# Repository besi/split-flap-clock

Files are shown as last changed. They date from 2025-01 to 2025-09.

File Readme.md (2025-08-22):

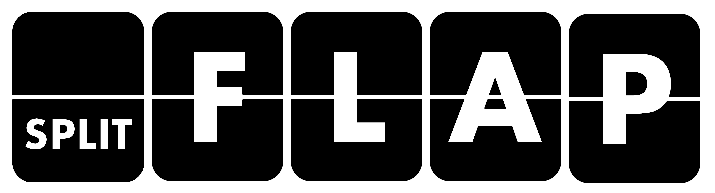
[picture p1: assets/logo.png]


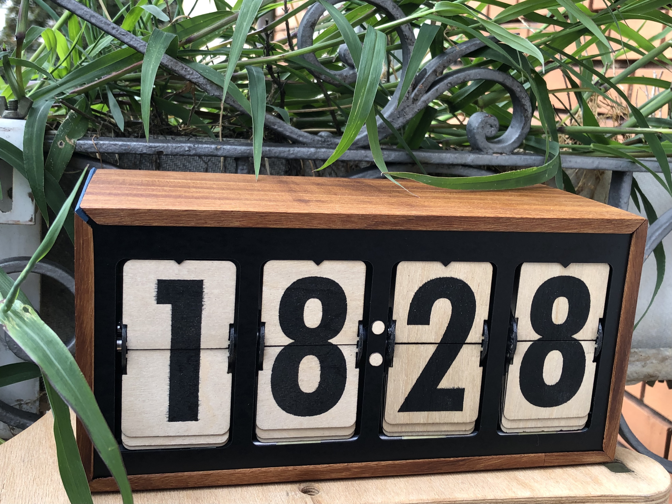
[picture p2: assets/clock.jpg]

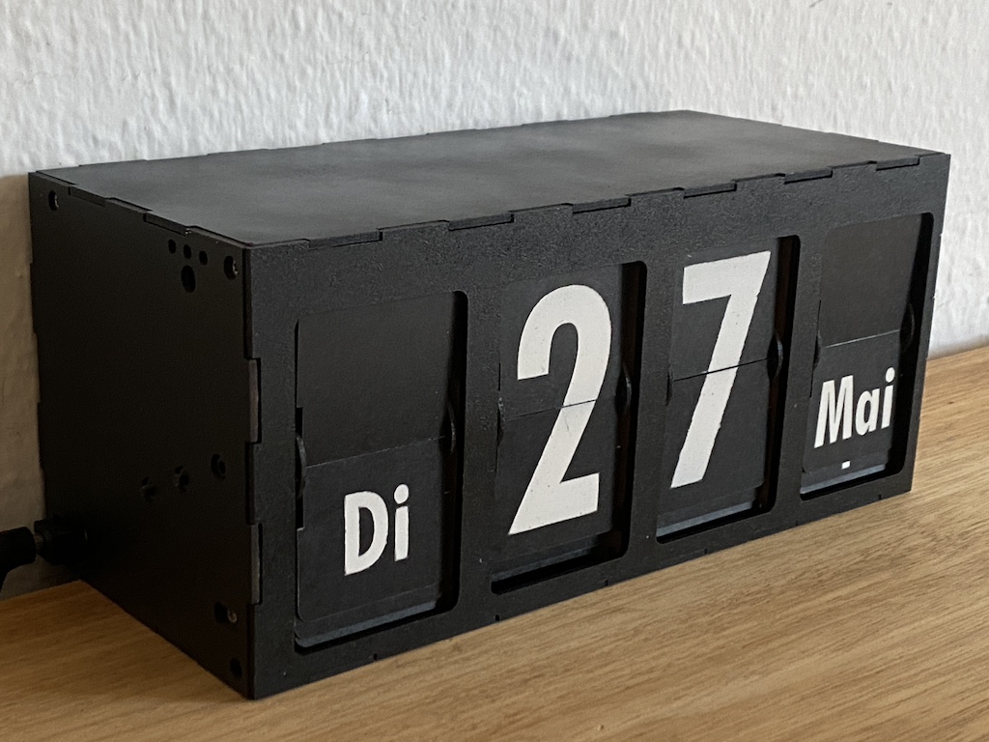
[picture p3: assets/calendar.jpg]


Split Flap clock or calendar utilising four 28BYJ-48 stepper motors.

## Bill of materials

What is needed for one digit.

| Count | Item | Description |
|---|---|---|
| 1 | PCB v2.0 | |
| 1 | Supporting Plate | Same shape and holes like the PCB |
| 1 | Spacer 2mm | Spacer for cogwheels |
| 1 | Hall sensor AH1815-W7| For the unpopulated PCBs only |
| 1 | 10k Resistor 0306 | For the unpopulated PCBS |
| 1 | Spool | 3-D Print with M3 heat insert |
| 1 | Spool lid | 3-D Print |
| 1 | Cog Stepper | 3-D Print / Laser cut |
| 1 | Cog M3 | 3-D Print / Laser cut |
| 1 | Cog M3 Nut | 3-D Print / Laser cut |
| 1 | Magnet 2x1mm | For spool |
| 1 | Motor 28BYJ-48 | 5V Version |
| 1 | Motor gasket | Laser cut |
| 12 | Flaps | Laser cut Flaps |
| 1 | 3 Pos JST 2mm Socket | Hall sensor Connection |
| 1 | 3 Pos JST 2mm Cable  | Hall sensor Connection |
| 4 | M3 Nuts | 2 Cogs, 2 Motor |
| 5 | M3x8mm Bolt | 2 Cogs,2 Motor, Spindle, |
| 3 | M3x5mm Bolt | 3 Spindle |
| 4 | M3 Standoffs 50mm | Male-Female 6mm thread |
| 4 | M2.5 Screws | For Standoffs |
| 1 | Washer 5mm 1mm thick | For Driver cogwheel |
| 2 | Washer 3mm 1mm thick | For cogwheels |
| 1 | Zip tie for motor | |

## Pinout

Motors: 

| Pins | 1  | 2  | 3  | 4  | Hall  |
|---|----|----|----|----|---|
| **Motor A** | 10 | 9  | 3  | 8  | 18 (7)|
| **Motor B** | 13 | 14 | 21 | 11 | 12 |
| **Motor C** | 40 | 39 | 38 | 6  | 47 |
| **Motor D** | 1  | 2  | 42 | 41 | 48 |

Other GPIOs

| Function | Pin |
|---|-----|
| DCF-77 | 4 |
| SDA / Switch B | 16  |
| SCL / Switch A | 17  |
| Mode | 0 |
| Neopixel | 15  |
| Temperature | 5 |

## Assembly

One assembled PCB which functions as the main board can drive four split flap digits including itself as well as three additional passive digits. Looking from the front of the clock / calendar the unit with the populated PCB is to the very left with the barrel jack protruding outward to the left side.

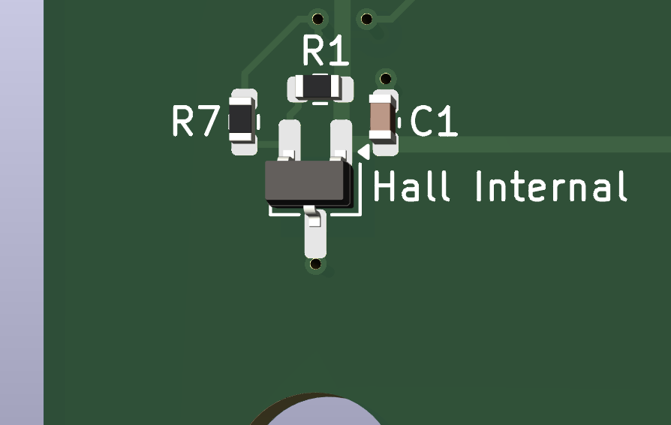
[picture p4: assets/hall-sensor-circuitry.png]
a
- On the three unpopulated PCBs the Hall sensors circuitry above the spool axis has to be provided. For this R7 can be shortened using a solder bridge, the Hall sensor (AH1815-W7) as well as the R1 resistor (10k 0603) need to be mounted. C1 (100nF 0603) can be omitted:  

- Using M3x5 screws mount all four motors directly to the corresponding PCB using the spacer where it says "28BYJ-48". The nuts go to the other side of the PCB where the spacer has two cutouts for both nuts.

- On the main board connect the motor to the "Motor A" connector. The cable can be looped and secured using a zip tie threaded through the two holes next to the motor.

- On the main board solder the three switches and the RGB LED to the backside of the PCB.

- Solder the DCF77 connector to the pcb and temporarily tape the ferrite antenna to the PCB to protect the thin copper wires from the coil around the antenna.

- Add cog wheels with the M3x8 screws on two different sides
- Add the spacer
- Add the cover
- Connect all hall sensors
- Prepare the spool 
- Add standoffs female-female or standoffs male-female respectively

- The driving cog wheel is assembled as follows:

        M3x16 + 5 washers + m3-nut-cog + 3 washers

## The PCB

[PCBWay][pcbway] kindly offered to sponsor the manufacturing and assembly of the second iteration of this pcb.

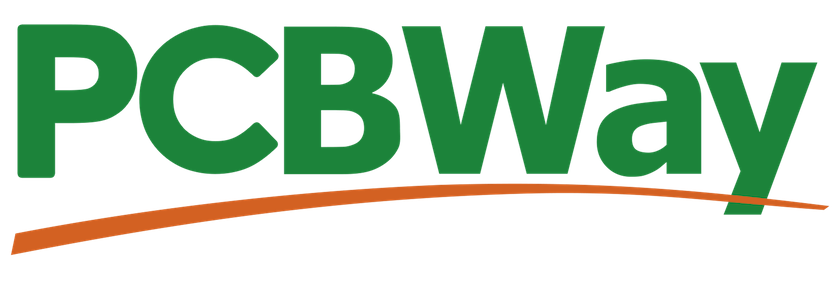
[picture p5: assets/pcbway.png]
PCBWay
[][pcbway]

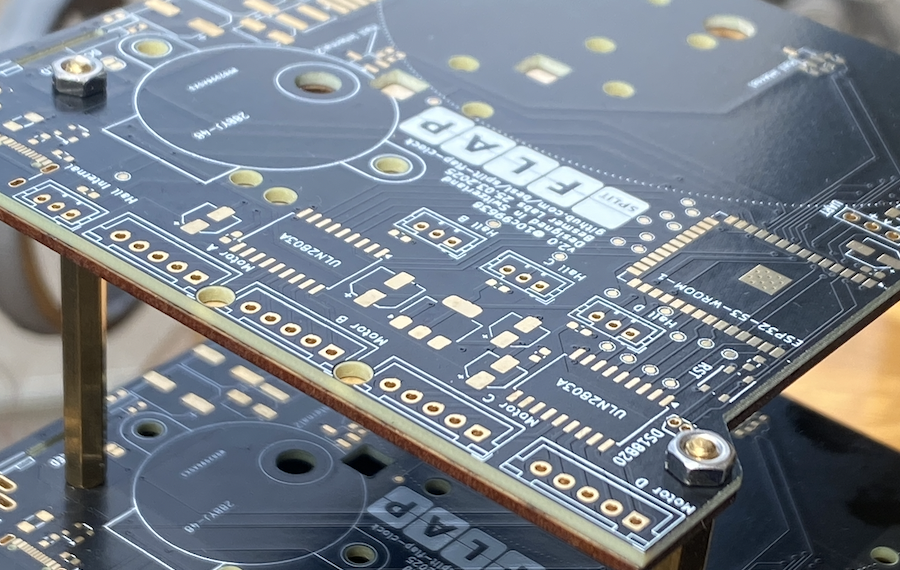
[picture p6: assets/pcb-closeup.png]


In this project the PCBs are used in both the electrical as well as the mechanical realm. The motors and cog wheels are directly mounted onto the pcb and for one clock or calendar four pcbs are stacked together.

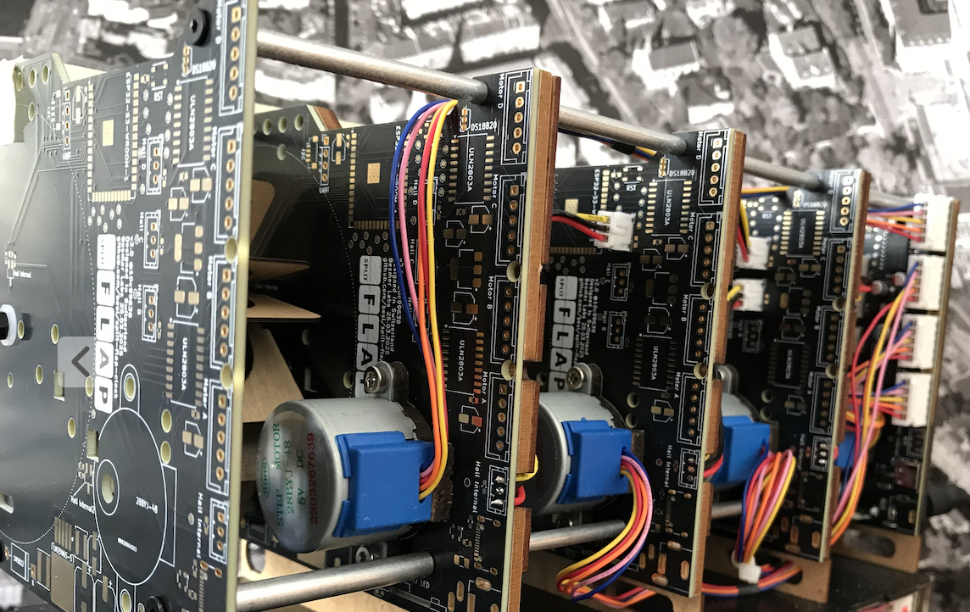
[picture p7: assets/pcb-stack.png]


The PCBs turned out flawlessly and the ordering process was smooth and efficient.

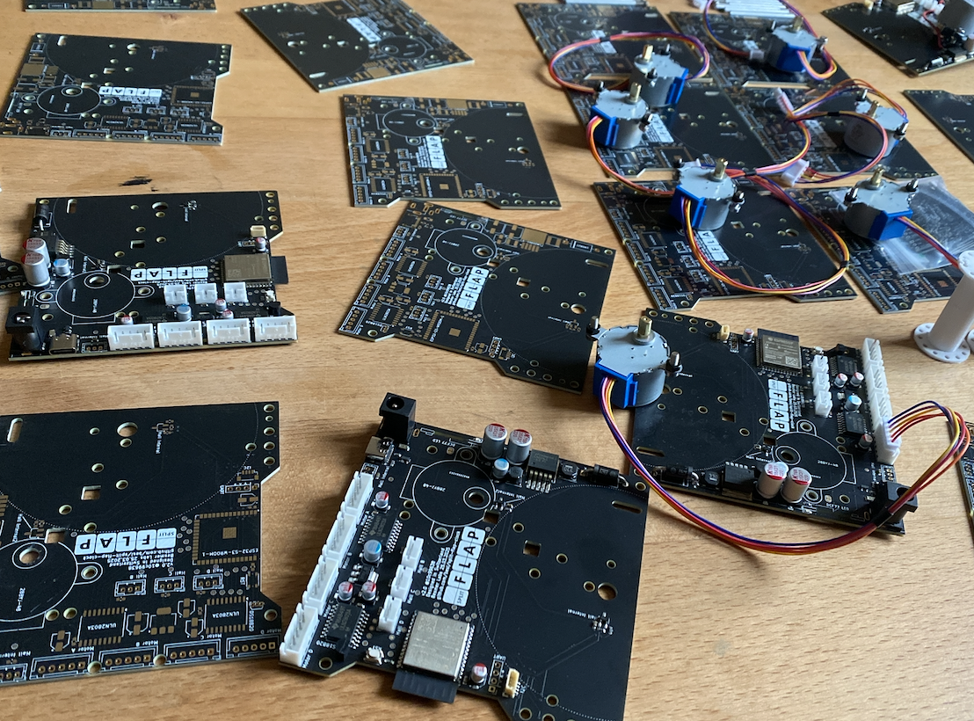
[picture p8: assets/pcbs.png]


[pcbway]: https://pcbway.com/g/2jc702

### PCB V2.0
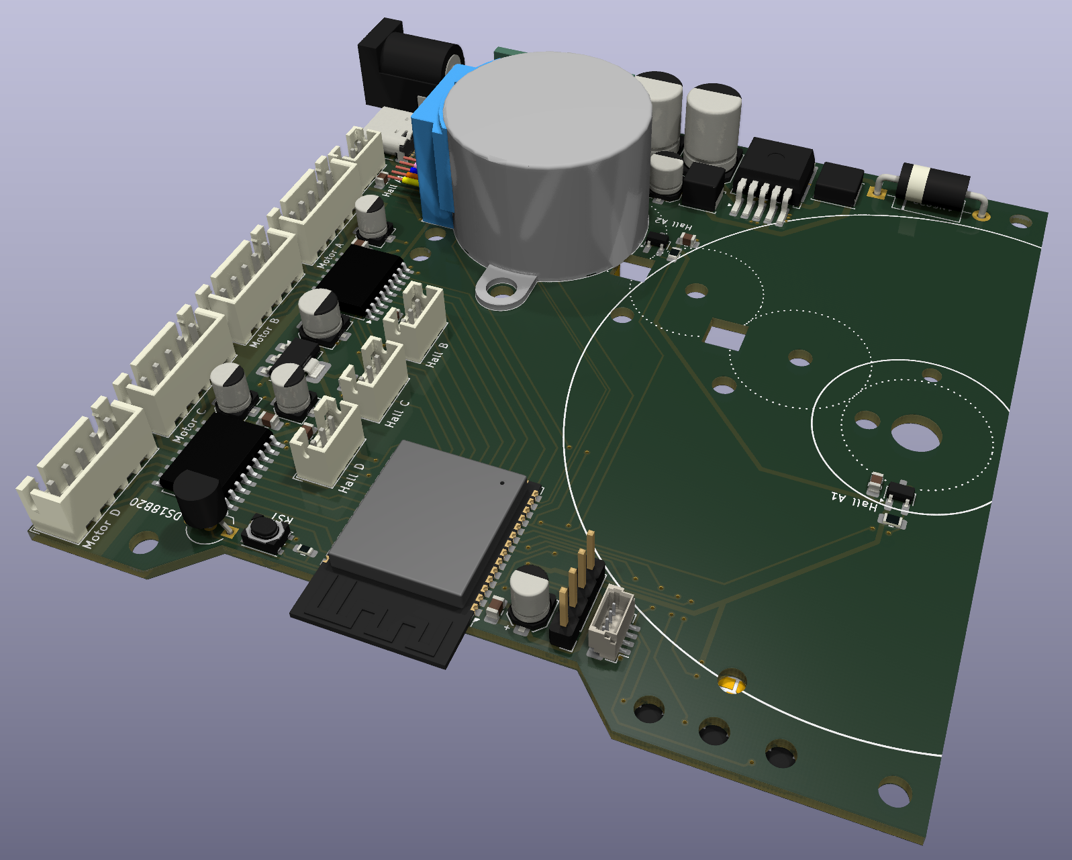
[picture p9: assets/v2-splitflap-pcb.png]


### PCB V1.0

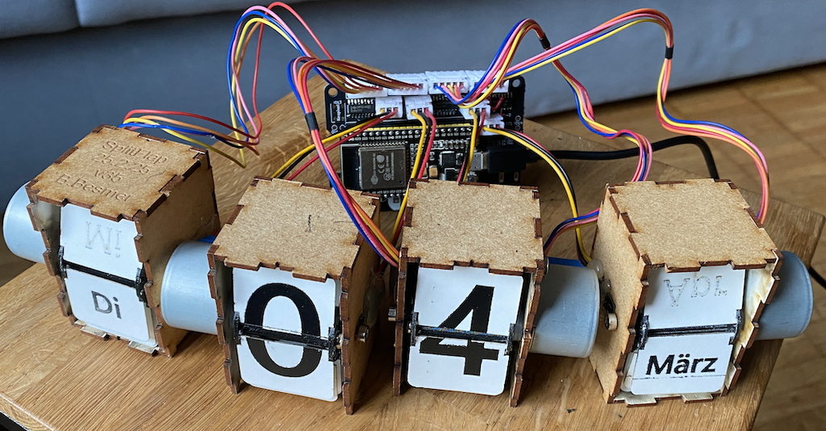
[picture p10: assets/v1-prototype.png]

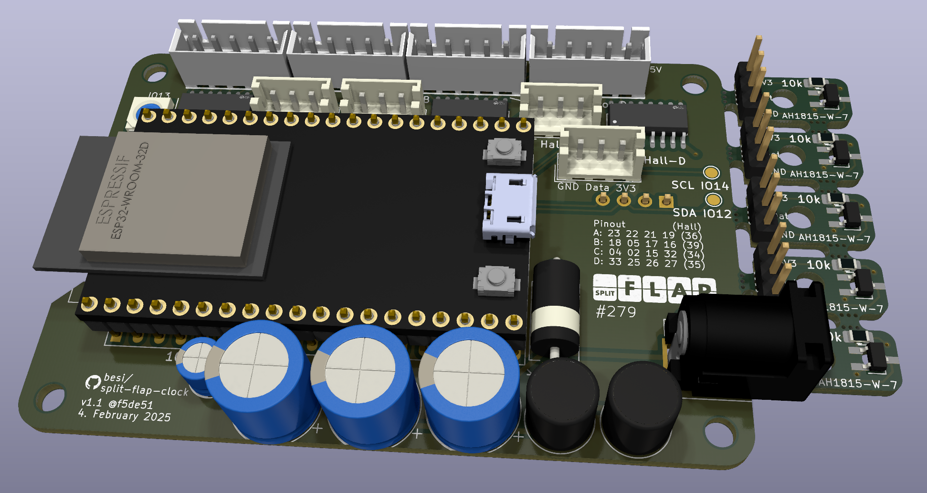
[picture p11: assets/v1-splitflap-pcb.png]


## Flashing the PCB

    cd ~/Downloads
    IMAGE=ESP32_GENERIC_S3-FLASH_4M-20250415-v1.25.0.bin
    wget https://micropython.org/resources/firmware/$IMAGE -nc
    PORT=/dev/cu.usbmodem14401
    esptool.py --port $PORT erase_flash
    esptool.py --port $PORT --baud 460800 write_flash --flash_size=detect 0 $IMAGE --flash_mode=dout

## Credits / Thanks

### Troubleshooting

Special thanks to [greybeard](https://electronics.stackexchange.com/users/274544/greybeard) and [KubaO](https://electronics.stackexchange.com/users/10810/kuba-hasnt-forgotten-monica) who helped to [trouble shoot](https://electronics.stackexchange.com/questions/740221/cross-talk-issues-with-uln2003-and-28byj-48-stepper) some serious issues that arose during the development of the PCB.

### 3D models
- Credits for the [ESP32 Devkit 3d model](https://grabcad.com/library/esp32-devkitc-v4-1) by [Andrei Golyakov](https://grabcad.com/andrei.golyakov-1)
- Credits for the [SK6814mini 3d model](https://grabcad.com/library/sk6812-mini-sk6814-smd3535-1) by [Laur V](https://grabcad.com/laur.v-1)

### Markdown tables

The Markdown tables were generated using the fabulous tool called [tableconvert](https://tableconvert.com/markdown-generator).

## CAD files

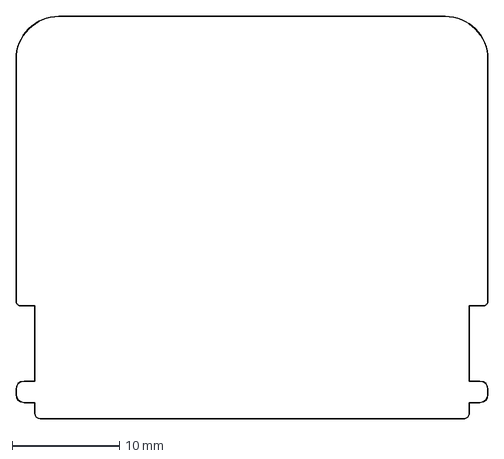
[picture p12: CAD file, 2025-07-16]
dxf/v2/Flap.dxf
44.0 x 37.5 mm

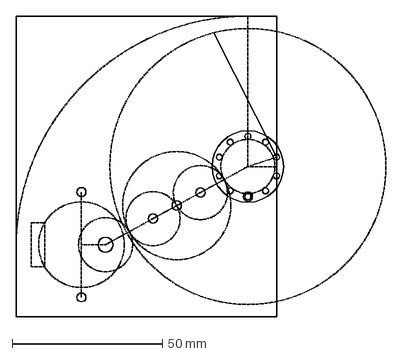
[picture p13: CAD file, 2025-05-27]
stl/v1-2/PCBOutline.dxf
122.9 x 100.0 mm

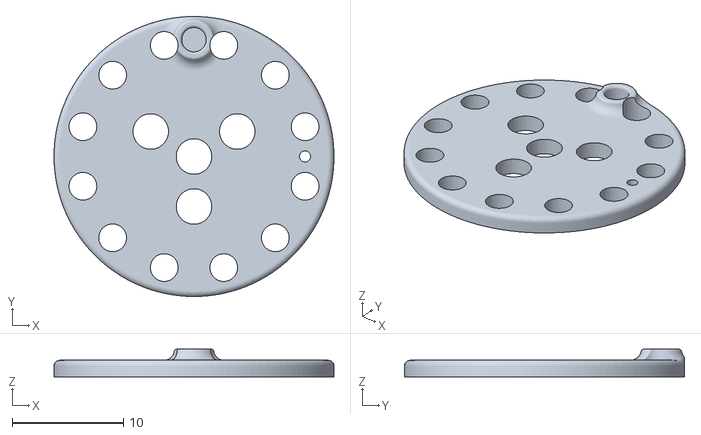
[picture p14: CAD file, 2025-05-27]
stl/v2/spool-lid.stl
25.2 x 25.2 x 2.50

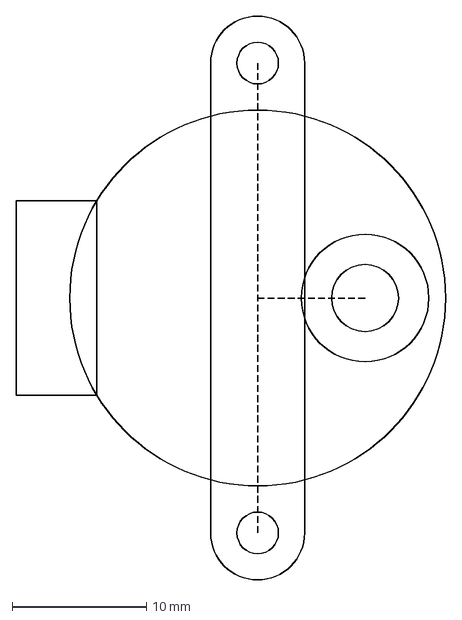
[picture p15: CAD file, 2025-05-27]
dxf/v2/MotorSpacerCork-T1.dxf
32.0 x 42.0 mm

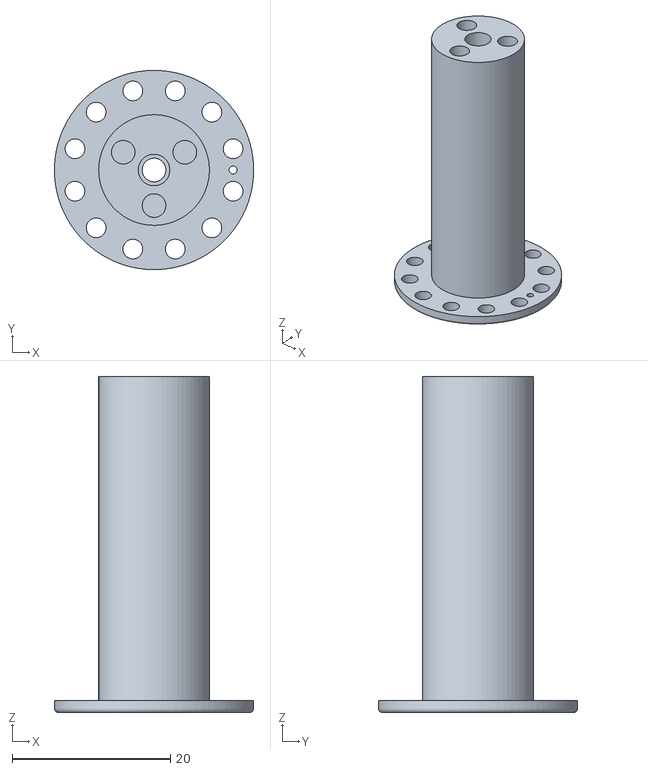
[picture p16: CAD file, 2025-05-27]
stl/v2/spool-base.stl
25.2 x 25.2 x 42.5

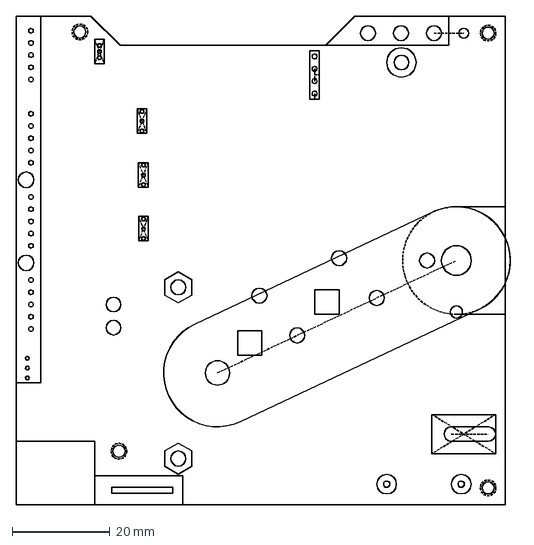
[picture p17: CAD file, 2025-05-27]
dxf/v2/Backplate-Spacer-T3.dxf
102.5 x 100.0 mm

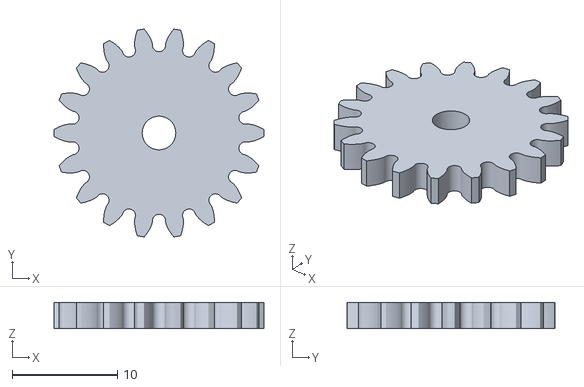
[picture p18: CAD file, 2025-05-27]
stl/v2/cog-n18-m1-t1-8-hole-m3.stl
20.0 x 19.8 x 2.50

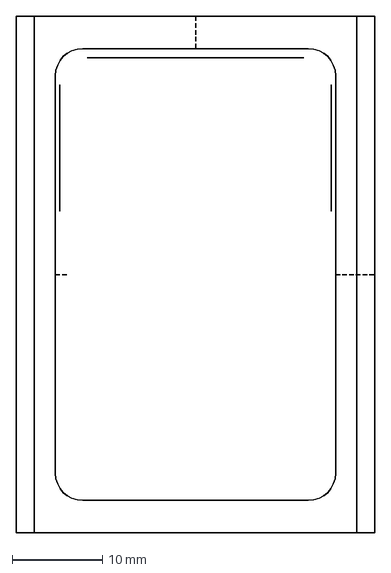
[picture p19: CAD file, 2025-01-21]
dxf/v2/2mm-front.dxf
39.7 x 57.1 mm

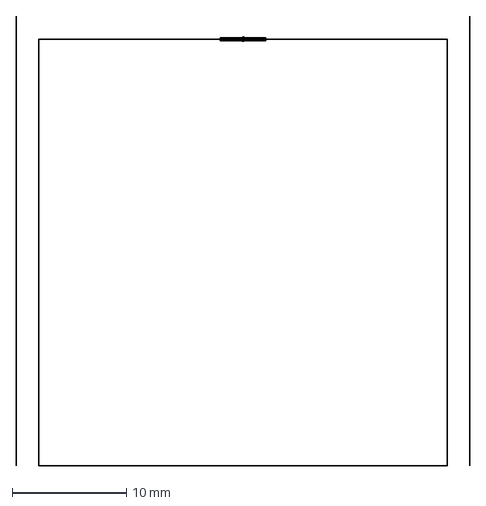
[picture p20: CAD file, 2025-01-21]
dxf/v2/2mm-top.dxf
39.7 x 39.3 mm

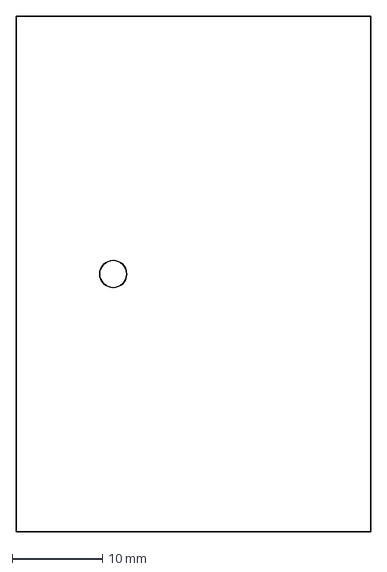
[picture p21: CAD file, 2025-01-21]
dxf/v2/2mm-right.dxf
39.3 x 57.1 mm

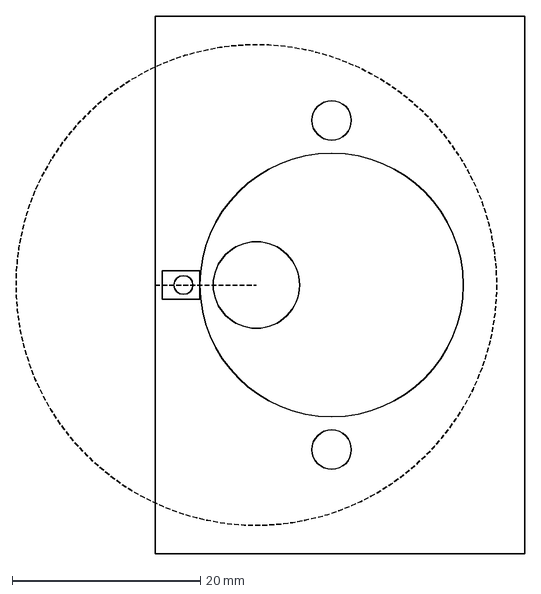
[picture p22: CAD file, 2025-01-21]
dxf/v2/2mm-left.dxf
54.1 x 57.1 mm

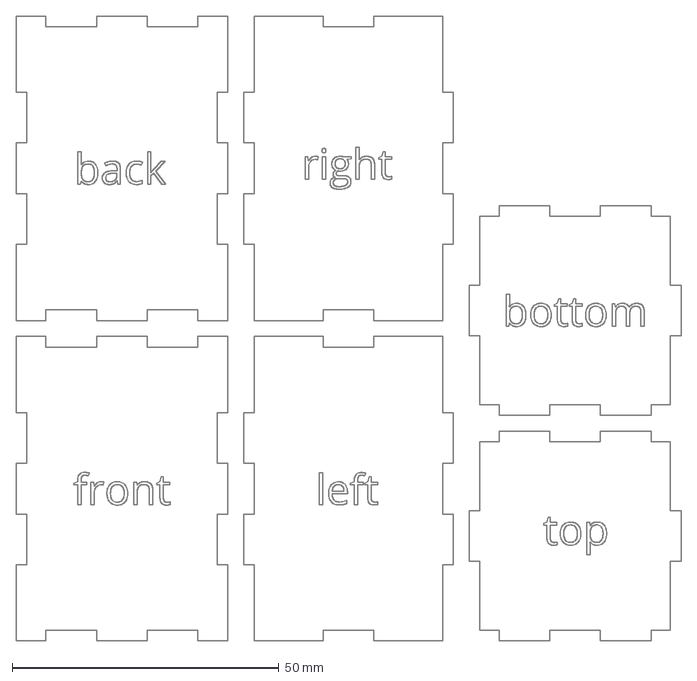
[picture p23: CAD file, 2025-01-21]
dxf/v2/2mm-w39-7-h57.1-d39-32-32-finger-9.5-outside.dxf
124.7 x 117.2 mm

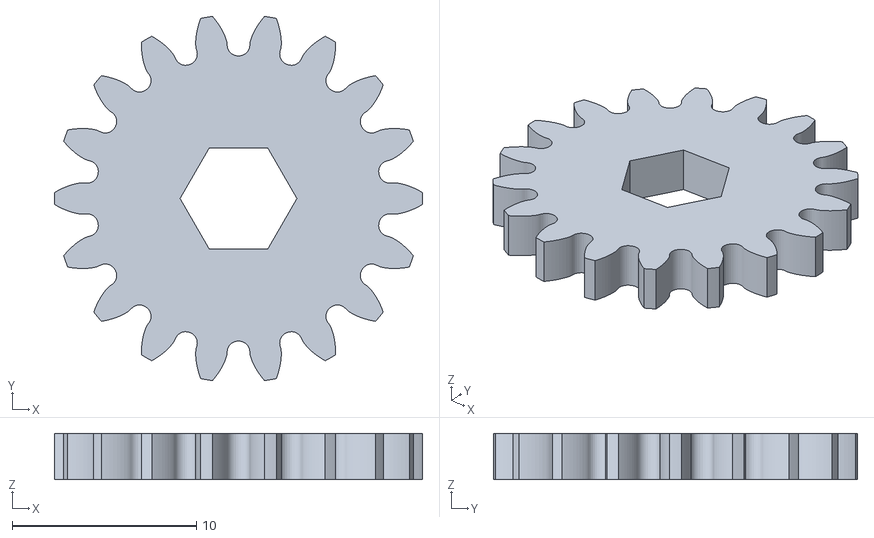
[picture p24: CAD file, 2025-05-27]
stl/v2/cog-n18-m1-t1-8-m3-nut.stl
20.0 x 19.8 x 2.50

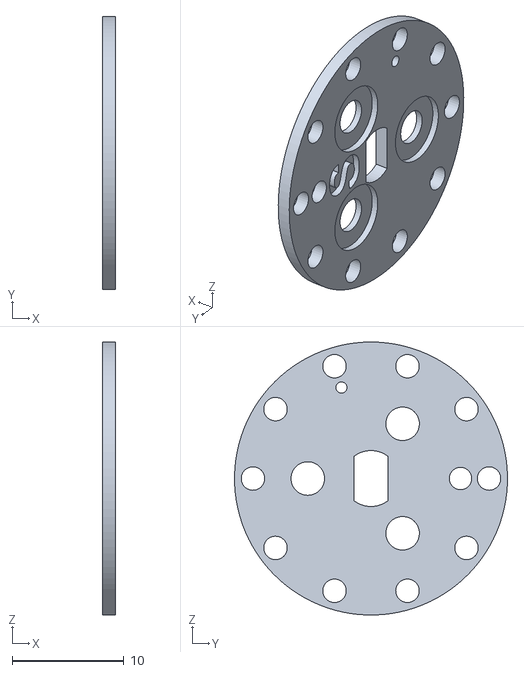
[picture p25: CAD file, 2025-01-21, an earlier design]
dxf/v1/driving front.stl
1.20 x 24.4 x 24.4

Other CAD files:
dxf/v2/flaps-pair.dxf
dxf/v2/flap-toucher.dxf
stl/v2/cog-n18-m1-t1-8-slotted5mm.stl
dxf/v1/2mm-makercase-outer-40-4--80-9--45-58.dxf
dxf/v1/2mm-front.dxf
dxf/v1/2mm-left.dxf
dxf/v1/2mm-right.dxf
dxf/v1/3mm-front.dxf
dxf/v1/3mm-left.dxf
dxf/v1/3mm-makercase-outer-3mm-x43-4-y80-9-z47-17.dxf
dxf/v1/3mm-right.dxf

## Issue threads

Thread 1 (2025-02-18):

Hardware test v1.0

besi, 2025-02-18:
- [x] Hall Sensors
- [x] Motor A
- [x] Motor B
- [x] Motor C
- [x] Motor D
- [x] Buttons
- [x] Neopixel not working
- [x] I2C

Results

- [x] #2
- [x] #3

Closed 2025-05-17.

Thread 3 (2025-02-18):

Motors not working due to the wrong package

besi, 2025-02-18:
Stepomatic's ULN2003 seems more narrow and uses by ti 32CCETK ULN2003A

besi, 2025-02-18:
Digikey lists the following packages

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

besi, 2025-02-18:
Package was fixed but there are still problems.

Motor C and Motor D work now on two pcbs

- Motor A: Pin 3 does not work
- Motor B: Pin 2 does not work
- Motor B: Pin 3 do not work

Closed 2025-02-18.

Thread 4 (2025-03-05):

Redesign

besi, 2025-03-05:
The next design iteration should include the following:

- [ ] Include the feedback from the [SO-Thread](https://electronics.stackexchange.com/questions/740221/cross-talk-issues-with-uln2003-and-28byj-48-stepper)
- [ ] Feature some mounts for cog-wheels and possibly the motor for the split flap display
- [ ]

besi, 2025-03-05:
@KubaO have a look at the new design constraints. While my initial design on SO was v1.0 and I might actually order a design 1.1 with your changes in them.

This issue here talks about version 2.0 where the PCB is tightly mechanically integrated in the design.

besi, 2025-03-08:
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

besi, 2025-03-08:
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

besi, 2025-03-10:
@KubaO. I made a draft of a PCB that serves as the mount of the motor and as a structural element. The glassy cylinder is the space that the flaps will occupy. There will be a second pcb without parts sandwiched ontop in order to make a tight enclosure for the gear train and then this will thing can be copy and pasted four times to form one unit.

besi, 2025-03-12:
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

besi, 2025-05-03:
Fixed and proceeding with #7

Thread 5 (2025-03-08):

On the fly calibration

besi, 2025-03-08:
Currently at power up a calibration sequence is done.
However after several turns the spool gets out of phase and some digits fall pre-maturely. Also because 513 / 10 is not a hole number.

- [x] When the spool goes past the known magnet point make a quick calibration and update the zero point

Optional:
- [ ] Compensate the three steps in between moves

besi, 2025-06-15:
If the correction is merely done by changing the position then the digit will update even though the same letter is still displayed.

besi, 2025-06-15:
The correction should be corrected over time by occasionally skipping some steps or doing extra steps.

Closed 2025-06-14.

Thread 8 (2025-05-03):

12V circuitry trips the resettable fuse

besi, 2025-05-03:

besi, 2025-05-03:
A workaround is to separate the 5V circuit from the 12V circuitry

besi, 2025-05-17:
The power socket was soldered on the wrong side of the PCB creating a short.

Closed 2025-05-17.

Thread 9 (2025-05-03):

Flashing poses a problem

besi, 2025-05-03:
When selecting the port there is a message:

invalid header: 0xffffffff
invalid header: 0xffffffff
invalid header: 0xffffffff
invalid header: 0xffESP-ROM:esp32s3-20210327
Build:Mar 27 2021
rst:0x7 (TG0WDT_SYS_RST),boot:0x8 (SPI_FAST_FLASH_BOOT)
Saved PC:0x40048839

besi, 2025-05-03:
After flashing the chip there is a new message:

OSError: (-24579, 'ESP_ERR_FLASH_NOT_INITIALISED')

besi, 2025-05-03:
Try to detect the flash size: does not work
Try with 4MB like the BOM lists:

<!-- Failed to upload "Screenshot 2025-05-03 at 21.20.19.png" -->

besi, 2025-05-03:
Seemed to have bricked one of the boards unixb0y/Micropython-ESP32-S3-WROOM-1-N4#1

besi, 2025-05-04:
Using the 4MB flash image did the trick:
https://micropython.org/resources/firmware/ESP32_GENERIC_S3-FLASH_4M-20250415-v1.25.0.bin

Closed 2025-05-04.

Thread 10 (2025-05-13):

Power issues

besi, 2025-05-13:
Unable to connect to /dev/cu.usbmodem14501: [Errno 2] could not open port /dev/cu.usbmodem14501: [Errno 2] No such file or directory: '/dev/cu.usbmodem14501'

Enabling Wifi seems to draw too much power.

besi, 2025-05-17:
Tried to short the fuse.
No immediate effect

besi, 2025-05-17:
Setting thE RX power

Closed 2025-05-27.

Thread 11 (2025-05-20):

Digit d2 looses steps

besi, 2025-05-20:
Digit 2 looses steps

- [x] Make sure it's not a mechanical issue by switching out two motors and hall sensors

## Observations

- The initial calibration is smooth and quick
- Then the MQTT starts and connects and when a message is received and displayed the display looses steps and displays the wrong numbers.
- In the normal date mode the problem does not seem to occur

## Thoughts

- The Wifi connectivity could be posing some issues since the normal date mode seems to work
- [ ] Use an oscilloscope to check out the signal integrity

besi, 2025-05-20:
The issue was caused due to a software bug which initialised pins from the motor as inputs

Closed 2025-05-20.

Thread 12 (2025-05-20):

Cog screws tighten themselves

besi, 2025-05-20:

besi, 2025-05-20:
A fix would be to mount the cogs with a m3 washer on the inside functioning as an bearing

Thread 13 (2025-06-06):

Infidelities when painting the Flaps

besi, 2025-06-06:
The Laser cutting process has speed and power issues

Small shapes get more power

besi, 2025-06-06:
100 speed
13/11 power has more consistent results

besi, 2025-06-06:
Power below 10 would be helpful

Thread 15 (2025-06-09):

Cogwheels get stuck

besi, 2025-06-09:
Spacer cardboard is 2.8mm

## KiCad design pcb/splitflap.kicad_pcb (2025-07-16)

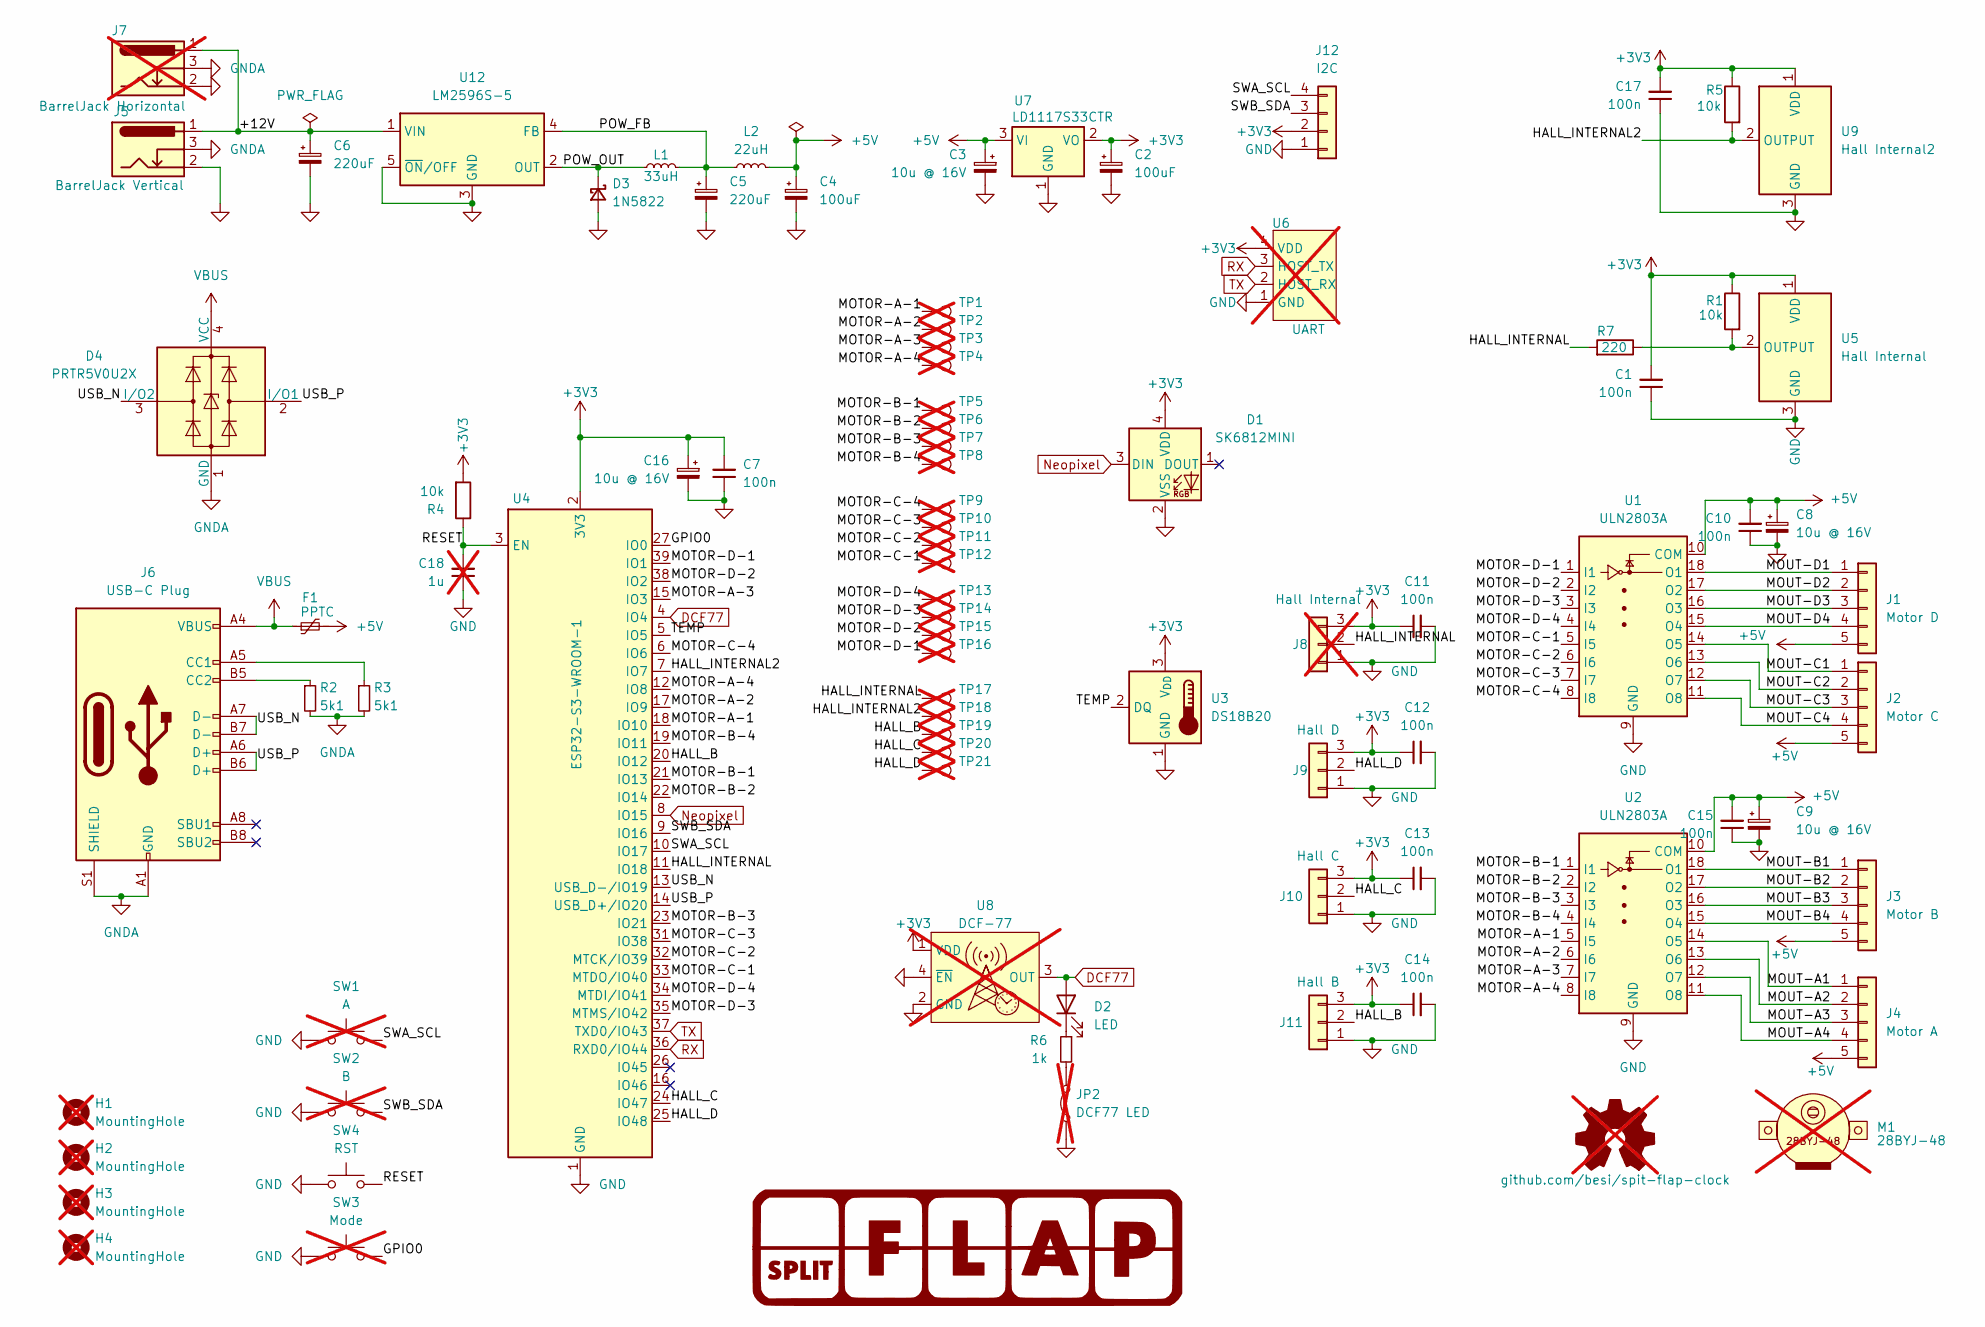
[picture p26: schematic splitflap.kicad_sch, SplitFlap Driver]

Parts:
C1, C7, C10, C11, C12, C13, C14, C15, C17: 100n; C_0603_1608Metric; MPN CL10E104KC8VPNC
C2, C4: 100uF; CP_Elec_5x5.3; MPN APXG160ARA101ME61G
C3, C8, C9, C16: 10u @ 16V; CP_Elec_4x5.7; MPN 865080340001
C5, C6: 220uF; CP_Elec_8x11.9; MPN A768KS227M1VLAE024
C18: 1u; C_0805_2012Metric_Pad1.18x1.45mm_HandSolder; MPN CL21B105KOFNNNG; not fitted
D1: SK6812MINI; LED_SK6812MINI_PLCC4_3.5x3.5mm_P1.75mm; MPN 1528-1541-ND
D2: LED; LED_0603_1608Metric_Pad1.05x0.95mm_HandSolder; MPN 150060RS75000
D3: 1N5822; D_DO-201_P15.24mm_Horizontal; MPN 1N5822
D4: PRTR5V0U2X; SOT-143; MPN PRTR5V0U2X,215
F1: PPTC; Fuse_1206_3216Metric; MPN MF-NSMF110/16X-2
H1, H2, H3, H4: MountingHole; MountingHole_3.2mm_M3; MPN X; LCSC DNP; not fitted
J1: Motor D; JST_XH_B5B-XH-A_1x05_P2.50mm_Vertical; MPN B5B-XH-A
J2: Motor C; JST_XH_B5B-XH-A_1x05_P2.50mm_Vertical; MPN B5B-XH-A
J3: Motor B; JST_XH_B5B-XH-A_1x05_P2.50mm_Vertical; MPN B5B-XH-A
J4: Motor A; JST_XH_B5B-XH-A_1x05_P2.50mm_Vertical; MPN B5B-XH-A
J5: BarrelJack Vertical; pj-060a; MPN CP-060A-ND
J6: USB-C Plug; USB_C_Receptacle_GCT_USB4105-xx-A_16P_TopMnt_Horizontal; MPN USB4105-GF-A
J7: BarrelJack Horizontal; BarrelJack_GCT_DCJ200-10-A_Horizontal; MPN 2073-DCJ200-10-A-K1-K-ND; not fitted
J8: Hall Internal; JST_PH_B3B-PH-K_1x03_P2.00mm_Vertical; MPN B3B-PH-K-S; not fitted
J9: Hall D; JST_PH_B3B-PH-K_1x03_P2.00mm_Vertical; MPN B3B-PH-K-S
J10: Hall C; JST_PH_B3B-PH-K_1x03_P2.00mm_Vertical; MPN B3B-PH-K-S
J11: Hall B; JST_PH_B3B-PH-K_1x03_P2.00mm_Vertical; MPN B3B-PH-K-S
J12: I2C; JST_SH_BM04B-SRSS-TB_1x04-1MP_P1.00mm_Vertical; MPN BM04B-SRSS-TB
JP2: DCF77 LED; SolderJumper-2_P1.3mm_Bridged_RoundedPad1.0x1.5mm; MPN X; not fitted
L1: 33uH; L_APV_ANR6028; MPN NR6028T330M
L2: 22uH; L_APV_ANR5045; MPN TYS5040220M-10
M1: 28BYJ-48; 28byj; MPN 28BYJ-48; not fitted
OSHW1: github.com/besi/spit-flap-clock; OSHW-Symbol_6.7x6mm_SilkScreen; MPN X; not fitted
R1, R5: 10k; R_0603_1608Metric; MPN CR0603-FX-1002ELF
R2, R3: 5k1; R_0603_1608Metric; MPN CR0603-FX-5101ELF
R4: 10k; R_0603_1608Metric_Pad0.98x0.95mm_HandSolder; MPN CR0603-FX-1002ELF
R6: 1k; R_0603_1608Metric; MPN CR0603-JW-102ELF
R7: 220; R_0603_1608Metric; MPN CR0603-JW-221ELF
SW1: A; SW_Push_1P1T_NO_Vertical_Wuerth_434133025816; MPN PTS815SJM250SMTRLFS; not fitted
SW2: B; SW_Push_1P1T_NO_Vertical_Wuerth_434133025816; MPN PTS815SJM250SMTRLFS; not fitted
SW3: Mode; SW_Push_1P1T_NO_Vertical_Wuerth_434133025816; MPN PTS815SJM250SMTRLFS; not fitted
SW4: RST; SW_Push_1P1T_NO_Vertical_Wuerth_434133025816; MPN PTS815SJM250SMTRLFS
TP1, TP2, TP3, TP4, TP5, TP6, TP7, TP8, TP9, TP10, TP11, TP12, TP13, TP14, TP15, TP16, TP17, TP18, TP19, TP20, TP21: TestPoint; TestPoint_Pad_D1.0mm; MPN X; not fitted
U1, U2: ULN2803A; SOP-18_7.495x11.515mm_P1.27mm; MPN 4518-ULN2803ATR-ND
U3: DS18B20; TO-92S; MPN 4518-DS18B20-ND
U4: ESP32-S3-WROOM-1; MPN ESP32-S3-WROOM-1-N4
U5: Hall Internal; SC-59_Handsoldering; MPN AH1815-W-7
U6: UART; PinHeader_1x04_P2.54mm_Vertical; MPN X; not fitted
U7: LD1117S33CTR; SOT-223-3_TabPin2; MPN LD1117S33CTR
U8: DCF-77; dcf77; MPN X; not fitted
U9: Hall Internal2; SC-59_Handsoldering; MPN AH1815-W-7
U12: LM2596S-5; TO-263-5_TabPin3; MPN 5399-LM2596S-5.0CT-ND

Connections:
+3V3: C1.2, C2.1, C7.2, C11.1, C12.1, C13.1, C14.1, C16.1, C17.2, D1.4 (VDD), J8.3, J9.3, J10.3, J11.3, J12.2, R1.1, R4.2, R5.1, U3.3 (V_{DD}), U4.2 (3V3), U5.1 (VDD), U6.4 (VDD), U7.2 (VO), U8.1 (VDD), U9.1 (VDD)
+5V: C3.1, C4.1, C8.1, C9.1, C10.2, C15.2, F1.2, J1.5, J2.5, J3.5, J4.5, L2.2, U1.10 (COM), U2.10 (COM), U7.3 (VI)
/+12V: C6.1, J5.1, J7.1, U12.1 (VIN)
/GPIO0: SW3.2, U4.27 (IO0)
/HALL_B: J11.2, TP19.1, U4.20 (IO12)
/HALL_C: J10.2, TP20.1, U4.24 (IO47)
/HALL_D: J9.2, TP21.1, U4.25 (IO48)
/HALL_INTERNAL: J8.2, R7.2, TP17.1, U4.11 (IO18)
/HALL_INTERNAL2: R5.2, TP18.1, U4.7 (IO7), U9.2 (OUTPUT)
/MOTOR-A-1: TP1.1, U2.5 (I5), U4.18 (IO10)
/MOTOR-A-2: TP2.1, U2.6 (I6), U4.17 (IO9)
/MOTOR-A-3: TP3.1, U2.7 (I7), U4.15 (IO3)
/MOTOR-A-4: TP4.1, U2.8 (I8), U4.12 (IO8)
/MOTOR-B-1: TP5.1, U2.1 (I1), U4.21 (IO13)
/MOTOR-B-2: TP6.1, U2.2 (I2), U4.22 (IO14)
/MOTOR-B-3: TP7.1, U2.3 (I3), U4.23 (IO21)
/MOTOR-B-4: TP8.1, U2.4 (I4), U4.19 (IO11)
/MOTOR-C-1: TP12.1, U1.5 (I5), U4.33 (MTDO/IO40)
/MOTOR-C-2: TP11.1, U1.6 (I6), U4.32 (MTCK/IO39)
/MOTOR-C-3: TP10.1, U1.7 (I7), U4.31 (IO38)
/MOTOR-C-4: TP9.1, U1.8 (I8), U4.6 (IO6)
/MOTOR-D-1: TP16.1, U1.1 (I1), U4.39 (IO1)
/MOTOR-D-2: TP15.1, U1.2 (I2), U4.38 (IO2)
/MOTOR-D-3: TP14.1, U1.3 (I3), U4.35 (MTMS/IO42)
/MOTOR-D-4: TP13.1, U1.4 (I4), U4.34 (MTDI/IO41)
/MOUT-A1: J4.1, U2.14 (O5)
/MOUT-A2: J4.2, U2.13 (O6)
/MOUT-A3: J4.3, U2.12 (O7)
/MOUT-A4: J4.4, U2.11 (O8)
/MOUT-B1: J3.1, U2.18 (O1)
/MOUT-B2: J3.2, U2.17 (O2)
/MOUT-B3: J3.3, U2.16 (O3)
/MOUT-B4: J3.4, U2.15 (O4)
/MOUT-C1: J2.1, U1.14 (O5)
/MOUT-C2: J2.2, U1.13 (O6)
/MOUT-C3: J2.3, U1.12 (O7)
/MOUT-C4: J2.4, U1.11 (O8)
/MOUT-D1: J1.1, U1.18 (O1)
/MOUT-D2: J1.2, U1.17 (O2)
/MOUT-D3: J1.3, U1.16 (O3)
/MOUT-D4: J1.4, U1.15 (O4)
/POW_FB: C5.1, L1.2, L2.1, U12.4 (FB)
/POW_OUT: D3.1 (K), L1.1, U12.2 (OUT)
/RESET: C18.2, R4.1, SW4.2, U4.3 (EN)
/SWA_SCL: J12.4, SW1.2, U4.10 (IO17)
/SWB_SDA: J12.3, SW2.2, U4.9 (IO16)
/TEMP: U3.2 (DQ), U4.5 (IO5)
/USB_N: D4.3 (I/O2), J6.A7 (D-), J6.B7 (D-), U4.13 (USB_D-/IO19)
/USB_P: D4.2 (I/O1), J6.A6 (D+), J6.B6 (D+), U4.14 (USB_D+/IO20)
DCF77: D2.2 (A), U4.4 (IO4), U8.3 (OUT)
GND: C1.1, C2.2, C3.2, C4.2, C5.2, C6.2, C7.1, C8.2, C9.2, C10.1, C11.2, C12.2, C13.2, C14.2, C15.1, C16.2, C17.1, C18.1, D1.2 (VSS), D3.2 (A), J5.2, J7.2, J8.1, J9.1, J10.1, J11.1, J12.1, JP2.1 (A), SW1.1, SW2.1, SW3.1, SW4.1, U1.9 (GND), U2.9 (GND), U3.1 (GND), U4.1 (GND), U4.40 (GND), U4.41 (GND), U5.3 (GND), U6.1 (GND), U7.1 (GND), U8.2 (GND), U8.4 (~EN), U9.3 (GND), U12.3 (GND), U12.5 (~ON/OFF)
GNDA: D4.1 (GND), J5.3, J6.A1 (GND), J6.A12 (GND), J6.B1 (GND), J6.B12 (GND), J6.S1 (SHIELD), J7.3, R2.2, R3.2
Neopixel: D1.3 (DIN), U4.8 (IO15)
unnamed: D2.1 (K), R6.1
unnamed: J6.A5 (CC1), R3.1
unnamed: J6.B5 (CC2), R2.1
unnamed: JP2.2 (B), R6.2
unnamed: R1.2, R7.1, U5.2 (OUTPUT)
RX: U4.36 (RXD0/IO44), U6.3 (HOST_TX)
TX: U4.37 (TXD0/IO43), U6.2 (HOST_RX)
VBUS: D4.4 (VCC), F1.1, J6.A4 (VBUS), J6.A9 (VBUS), J6.B4 (VBUS), J6.B9 (VBUS)

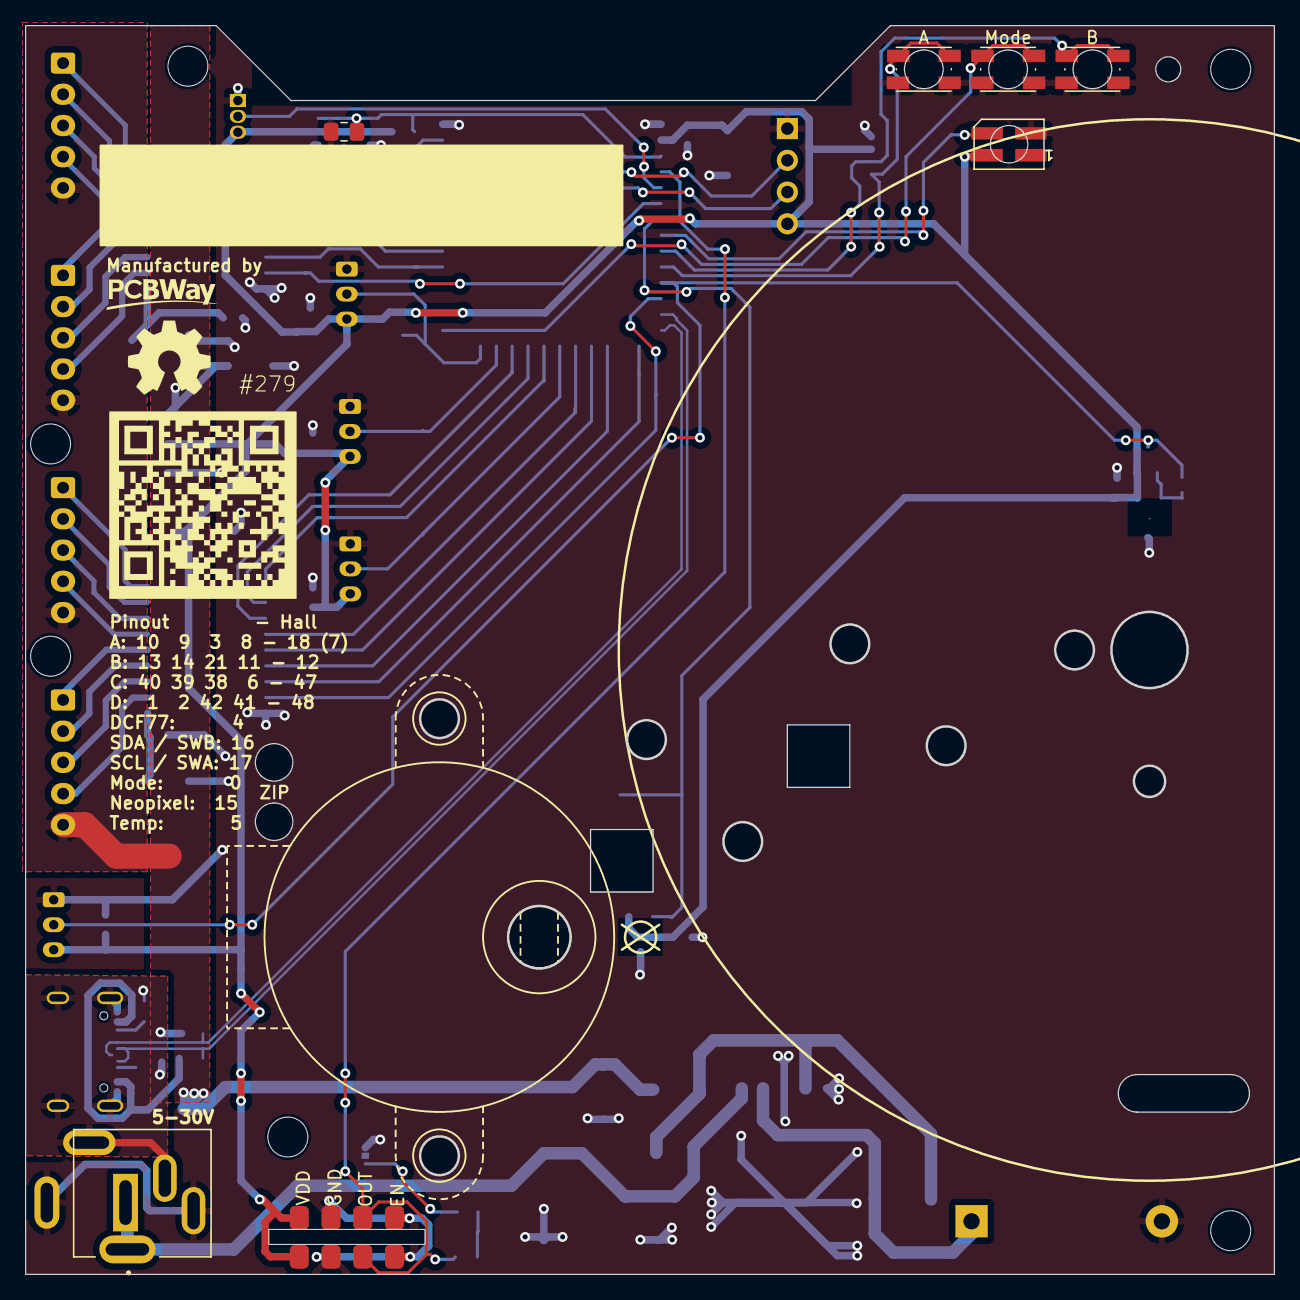
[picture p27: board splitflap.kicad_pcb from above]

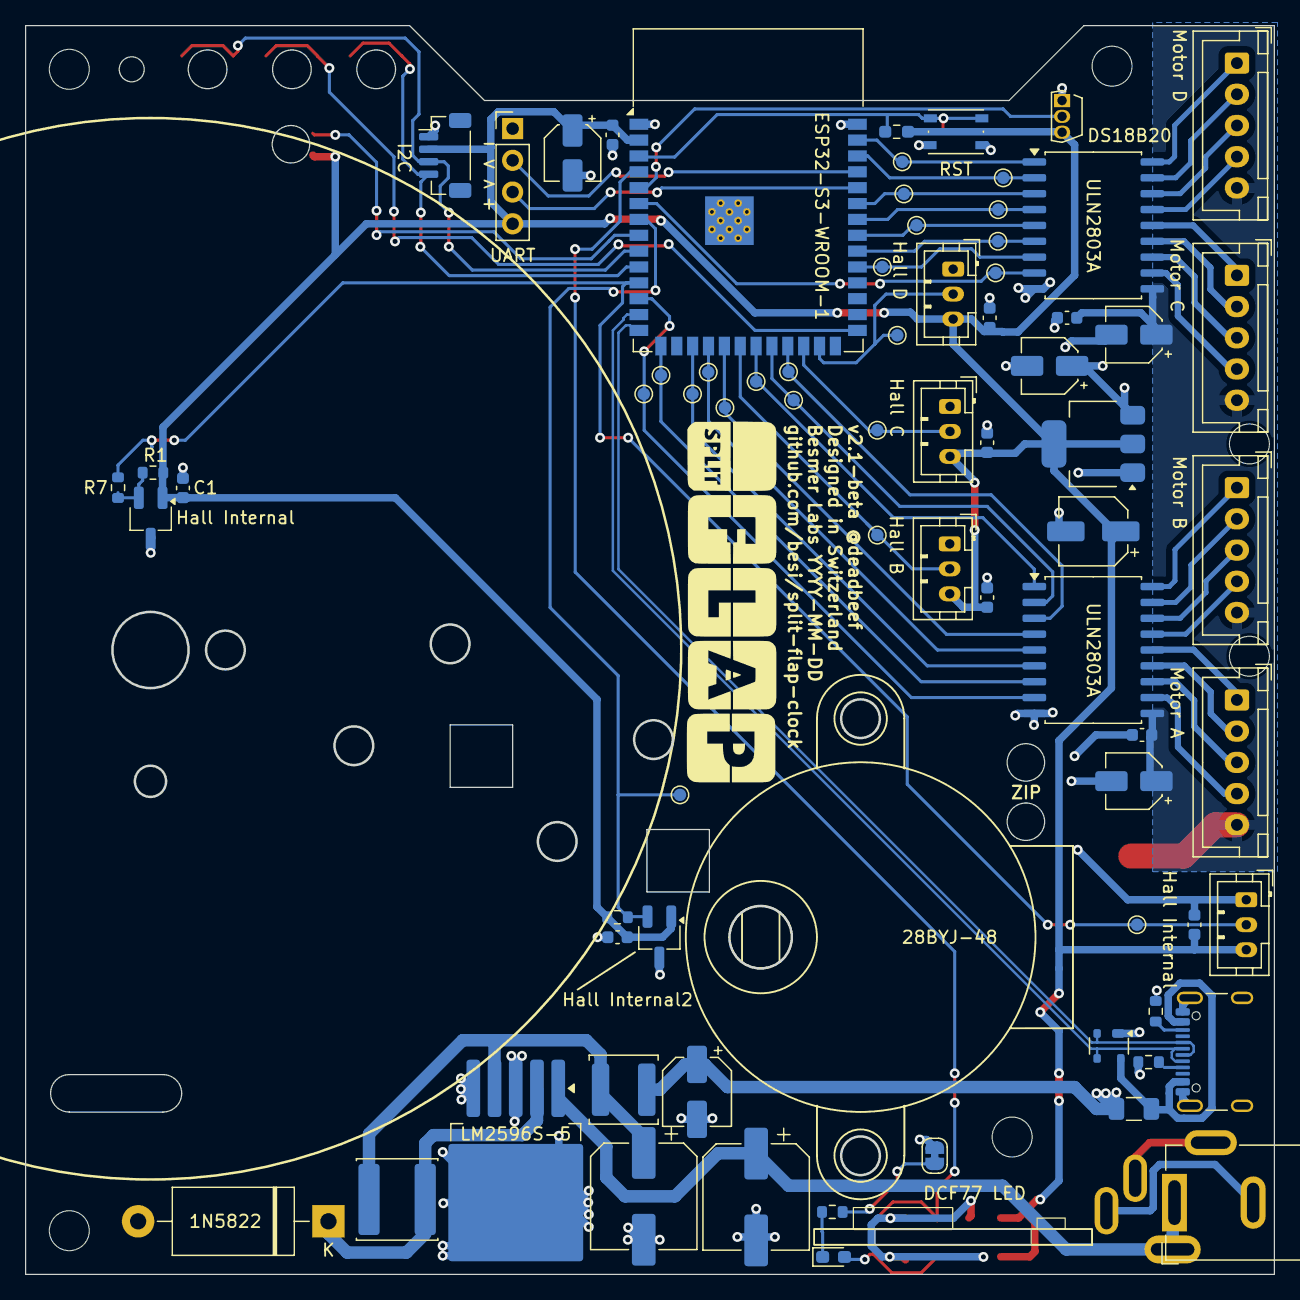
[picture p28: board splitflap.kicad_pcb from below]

Board: 2 copper layers, 100.0 x 100.0 mm, 88 parts (81 on the bottom side), 61 nets.

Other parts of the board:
H5, H6: MountingHole; MountingHole_3.2mm_M3

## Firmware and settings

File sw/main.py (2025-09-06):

from machine import Pin
from machine import ADC
import machine
import time
from digit import Digit
import neopixel

from uln2003 import Stepper, HALF_STEP, FULL_STEP, FULL_ROTATION, Driver, Command
from machine import Pin

d = 0.001
BLANK=11

(year,month,mday,h,m,s,weekday,yearday) = time.localtime()

c1 = -5
s1 = Stepper(HALF_STEP, Pin(10, Pin.OUT), Pin(9, Pin.OUT), Pin(3, Pin.OUT), Pin(8, Pin.OUT), d)
h1 = Pin(18, Pin.IN)
d1 = Digit(s1, h1, [0, 1, 2, 3, 4, 5, 6, 7, 8, 9, 10, 11], c1, 1, label='Weekdays')

c2 = -8
s2 = Stepper(HALF_STEP, Pin(13, Pin.OUT), Pin(14, Pin.OUT), Pin(21, Pin.OUT), Pin(11, Pin.OUT), d)
h2 = Pin(12,Pin.IN)
d2 = Digit(s2, h2, [0, 1, 2, 3, 4, 5, 6, 7, 8, 9, 10, 11], c2, 1, label='Days10')

c3 = -7
s3 = Stepper(HALF_STEP, Pin(40, Pin.OUT), Pin(39, Pin.OUT), Pin(38, Pin.OUT), Pin(6, Pin.OUT), d)
h3 = Pin(47, Pin.IN)
d3 = Digit(s3, h3, [0, 1, 2, 3, 4, 5, 6, 7, 8, 9, 10, 11], c3, 1, label='Days')

c4 = -40
s4 = Stepper(HALF_STEP, Pin(1, Pin.OUT), Pin(2, Pin.OUT), Pin(42, Pin.OUT), Pin(41, Pin.OUT), d)
h4 = Pin(48, Pin.IN)
d4 = Digit(s4, h4, [0, 1, 2, 3, 4, 5, 6, 7, 8, 9, 10, 11], c4, 1, label='Months')

# Buttons
mode = Pin(0, Pin.IN)
button_a = Pin(17, Pin.IN)
button_b = Pin(16, Pin.IN)
buttons = [mode, button_a, button_b]

# I2C
from machine import Pin, SoftI2C
scl = Pin(17, Pin.IN, Pin.PULL_UP)
sda = Pin(16, Pin.IN, Pin.PULL_UP)
i2c = SoftI2C(scl,sda)

np = neopixel.NeoPixel(machine.Pin(13),2)
#np.fill((1,1,1))
#np.write()

def showTime():
    (year,month,mday,h,m,s,weekday,yearday) = time.localtime()
    hour = int(h/10)
    if hour == 0: 
        d1.show(BLANK)
    else:
        d1.show(hour)
    d2.show(h%10)
    d3.show(int(m/10))
    d4.show(m%10)

d1.calibrate(); showTime()
d2.calibrate(); showTime()
d3.calibrate(); showTime()
d4.calibrate(); showTime()


def showDate():
    (year,month,mday,h,m,s,weekday,yearday) = time.localtime()
    d1.show(weekday)
    tens = int(mday/10)
    if tens == 0: 
        d2.show(BLANK)
    else:
        d2.show(tens)

    d3.show(mday%10)
    d4.show(month)

while True:
    showTime()
    time.sleep(10)
    

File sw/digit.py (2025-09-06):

from uln2003 import Stepper, HALF_STEP, FULL_ROTATION
import time
HALL_ACTIVE = 0

class Digit():
    def __init__(self, stepper, sensor, labels = [], offset = 0, direction = 1, label =''):
        self.stepper = stepper
        self.sensor = sensor
        self.labels = labels
        self.direction = direction
        self.position = -99999
        self.offset = offset
        self.label = label
        self.magnet_range = 0
        self.correction = 0
        self.is_calibrated = False
    
    def hall_active(self):
        return self.sensor() == HALL_ACTIVE

    def advance_to(self, position):
        position = round(position)
        print(f"Advance from {self.position} to {position}")
        if position > self.position:
            self.advance(position - self.position)
        elif position == round(self.position):
            print("Already there")
        else:
            print(f"Advance over zero to {FULL_ROTATION - self.position + position}")
            self.advance(FULL_ROTATION - self.position + position) 

    def show(self, label):
        if label in self.labels and self.is_calibrated:
            i = self.labels.index(label)
            self.advance_to(i * FULL_ROTATION / len(self.labels))

    def advance(self, steps):
        steps_left = round(steps - self.correction) % FULL_ROTATION
        self.correction = 0
        old = self.position
        self.position += steps
        if self.position < 0:
            self.position += FULL_ROTATION
            print(f"Added FULL_ROTATION to get to {self.position}")
        if self.position >= FULL_ROTATION:
            self.position -= FULL_ROTATION
            print(f"Removed FULL_ROTATION to get to {self.position}")
        start = -1
        end = -1
        
        while steps_left > 0:
            i = steps - steps_left
            self.stepper.step(1, self.direction)
            if self.hall_active() and start == -1:
               start = old + i
            if not self.hall_active() and start != -1:
                end = old + i 
                self.correction = round(FULL_ROTATION - (end - (end-start) / 2) - self.offset) % FULL_ROTATION
                start = -1
            steps_left -= 1
        correction_string = f"correction of {self.correction}" if abs(self.correction) > 0 else ''
        print(f"Went: {steps} steps from: {old} to: {self.position} {correction_string}") 


    def calibrate(self, move_to_first = False):
        print(f"Calibrating the {self.label} digit")
        print(f"{self.labels}")

        if self.hall_active():
            i = 0
            while self.hall_active():
                self.stepper.step(1, -self.direction)
                i += 1
            print(f"moved {i} out of the magnet area")

        i = 0
        print(f"Starting calibration")
        while not self.hall_active():
            self.stepper.step(1, self.direction)
            i += 1
            
        print(f"Found the magnet after {i} steps")
        i = 0
        while self.hall_active():
            i += 1
            self.stepper.step(1,self.direction)
        print(f"Reached end of hall sensor at {i}")
        self.magnet_range = i
        # Go to the magnet center
        self.stepper.step(int(i / 2), -self.direction)
        print("Set the absolute zero relative to the offset")
        self.position = FULL_ROTATION - self.offset
            
        if move_to_first:
            print("Go to offset")
            self.advance(self.offset)
        self.position = self.position % FULL_ROTATION
        print(f"calibration ended at position {self.position}")
        self.is_calibrated = True

if __name__ == '__main__':
    from machine import Pin  
    s1 = Stepper(HALF_STEP, Pin(10, Pin.OUT), Pin(9, Pin.OUT), Pin(3, Pin.OUT), Pin(8, Pin.OUT), 0.001)
    d1 = Digit(s1, Pin(18, Pin.IN), list(range(0,12)), -10, 1, label='Weekdays')
    d1.calibrate()
    d1.show(0)

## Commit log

2025-01-19 Add dxf for the case - v1
    [front.dxf, left.dxf, makercase-outer-3mm-x43-4-y80-9-z47-17.dxf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]
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2025-01-19 Fixed wrong material thickness
    [2mm-makercase-outer-40-4--80-9--45-58.dxf, front.dxf, left.dxf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]
2025-01-20 Add flaps of v2
    [v2-flaps.stl]
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2025-01-21 new case for v2
    [2mm-front.dxf, 2mm-left.dxf, 2mm-makercase-outer-40-4--80-9--45-58.dxf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]
2025-01-21 Add filet to front
    [2mm-front.dxf]
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2025-01-25 Add intial pcb for the split flap calender multi-motor setup
    [splitflap.kicad_pcb, splitflap.kicad_sch]
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2025-01-26 Silkscreen and hall sensor breakout cleanup
    [splitflap.kicad_pcb, splitflap.kicad_sch]
2025-01-26 Panelise the Hall sensor breakout
    [splitflap.kicad_pcb]
2025-01-26 Add a barrel jack and include all hall breakouts in the schematic
    [splitflap.kicad_pcb, splitflap.kicad_sch]
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2025-01-26 Add four buttons A, B, GPIO0 and RST
    [splitflap.kicad_pcb, splitflap.kicad_sch]
2025-01-26 Set the board origin for step export and prepare for next release
    [splitflap.kicad_pcb]
2025-01-28 Add esp 32 wroom step file
    [splitflap.kicad_pcb]
2025-01-29 Make sure mouse bites aren't deleted upon import
    [splitflap.kicad_pcb]
2025-02-03 Add 12V-enabled power supply
    [splitflap.kicad_pcb, splitflap.kicad_sch]
2025-02-04 Add missing footprint
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2025-02-09 Allow skipping the WIFI in boot.py
    [boot.py]
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2025-02-17 Make SOIC16 package of ULN2003 more wide and label both inductors with silkscreen
    [splitflap.kicad_pcb]
2025-02-17 Add package to schematic for SOIC16 ULN2003
    [splitflap.kicad_sch]
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2025-03-02 Update schematic to aid troubleshooting
    [splitflap.kicad_pcb, splitflap.kicad_sch]
2025-03-04 Fix wrong labels in PCB
    [splitflap.kicad_pcb, splitflap.kicad_sch]
2025-03-04 Fix an error with a reference to the wrong hall sensor
    [main.py]
2025-03-04 Rework 1
    Per EE.SO answer https://electronics.stackexchange.com/a/740530/10810
    [splitflap.kicad_pcb, splitflap.kicad_sch]
2025-03-04 Rework 2
    To be conservative, the traces driving the ULN2003s have been separated out, to prevent capacitive coupling between them. It's "cargo cult engineering", but since we can do it without trouble, how about we do it.
    [splitflap.kicad_pcb]
2025-03-04 Rework 3
    Now the signal flow is the recommended way: inputs far away from power outputs. The Hall sensor connectors have been moved to the front of the PCB.
    [splitflap.kicad_pcb, splitflap.kicad_sch]
2025-03-04 Rework 4
    The trace from the 12V input capacitor to the switcher ran on the bottom layer, making for a rather deep cut in the ground plane. This trace has been partially moved to the top layer, avoiding the cut.
    [splitflap.kicad_pcb]
2025-03-04 Rework 5
    The schematic was separated into two sheets, and made easier to follow.
    The Neopixels were connected in parallel. They should be in series.
    The I2C mezzanine board was centered relative to the ESP module.
    [sensors.kicad_sch, splitflap.kicad_pcb, splitflap.kicad_sch]
2025-03-05 Rework 6
    Added power flags to external power inputs. Fixed Motor connector pins from Unspecified to Passive, per KiCad fashion. Made the ERC pass without exclusions.
    Added power decoupling to Hall sensor connectors and to the Neopixels.
    Moved the IN test point for better probing accessibility. Test points use teardrop connections for integrity in face of probing.
    Added a ground clip area for scope probes etc.
    Added a 3D model of the pushbuttons.
    Rework 6
    Change revision to 1.2.
    [sensors.kicad_sch, splitflap.kicad_pcb, splitflap.kicad_sch]
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2025-03-08 Draft of v2 board to be imported in Fusion360
    [splitflap.kicad_pcb, splitflap.kicad_sch]
2025-03-11 SW: Add the corrections as a seperate variable
    [main.py]
2025-03-11 Allow to skip the offset move after the calibration in order to save revolutions at startup
    [digit.py, main.py]
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2025-03-14 Make the zip tie holes vertical
    [splitflap.kicad_pcb]
2025-03-14 Make cable winding holes bigger
    [splitflap.kicad_pcb]
2025-03-15 Small changes
    - Rename 4341x30258x6_rev1.stp to 434133025816.step
    [splitflap.kicad_pcb]
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2025-03-15 Add extra test point for IO7 and an additional hall sensor for Hall A
    [splitflap.kicad_pcb, splitflap.kicad_sch]
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2025-03-18 Added 3d model of the SK6812 mini
    [splitflap.kicad_pcb]
2025-03-20 Add optional LED for DCF receiver
    [splitflap.kicad_pcb, splitflap.kicad_sch]
2025-03-20 Add two Hall sensors to the current board so that the amount of backlash can be registered
    [splitflap.kicad_pcb, splitflap.kicad_sch]
2025-03-20 Remapping the motors ABCD to match the connectors on the board
    [splitflap.kicad_pcb, splitflap.kicad_sch]
2025-03-20 Add capacitors for hall sensors power pins
    [splitflap.kicad_pcb, splitflap.kicad_sch]
2025-03-20 DNP components and bigger pads for hand solder items
    [splitflap.kicad_pcb, splitflap.kicad_sch]
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2025-03-21 Add flap stop slot
    [splitflap.kicad_pcb]
2025-03-21 Add a PPTC fuse to the USB connection
    [splitflap.kicad_pcb]
2025-03-21 Add test points for motor input signals and hall sensors
    [splitflap.kicad_pcb, splitflap.kicad_sch]
2025-03-21 Use 0603 for resistors and capacitors
    [splitflap.kicad_pcb, splitflap.kicad_sch]
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2025-03-22 Add ESD protection for the USB-C socket
    [splitflap.kicad_pcb, splitflap.kicad_sch]
2025-03-22 Change package of the temperature sensor
    [splitflap.kicad_pcb, splitflap.kicad_sch]
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2025-03-23 Finalise the part’s MPN
    [splitflap.kicad_pcb, splitflap.kicad_sch]
2025-03-23 Unambiguous MPN for the TVS diode array
    [splitflap.kicad_pcb, splitflap.kicad_sch]
2025-03-23 Move silkscreen to Fab layers
    [splitflap.kicad_pcb]
2025-03-24 Populate the barrel jack on the back (if possible) and add a keep out zone for both hall sensors just in case
    [splitflap.kicad_pcb, splitflap.kicad_sch]
2025-03-24 Add logo to the PCB
    [splitflap.kicad_pcb]
2025-03-24 Silkscreen: Logo / Date / Commit Placeholder / Labels / PCB Way logo
    [splitflap.kicad_pcb, splitflap.kicad_sch]
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2025-03-25 Fix HALL_INTERNAL label
    The layout is not affected
    [splitflap.kicad_pcb, splitflap.kicad_sch]
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2025-03-25 Move vias out of the pads
    [splitflap.kicad_pcb]
2025-03-25 Correlate footprints according to the feedback from the Fab-house
    [splitflap.kicad_pcb, splitflap.kicad_sch]
2025-03-25 Add step model for the NR6028T330M inductor
    [splitflap.kicad_pcb]
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2025-03-26 Prepare for next release
    [splitflap.kicad_pcb, splitflap.kicad_sch]
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2025-04-10 Add v1.2 stl files
    [flap.stl, spool-lid.stl, spool-n12.stl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]
2025-04-10 Add stl files based on fusion v19
    [spool-base.stl, spool-lid.stl]
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2025-04-10 Add pcb for making support plates
    [PCBOutline.dxf]
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2025-05-07 Add cog wheels as stl epxports
    [cog-n18-m1-t1-8-hole-m3.stl, cog-n18-m1-t1-8-m3-nut.stl, cog-n18-m1-t1-8-slotted5mm.stl]
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2025-05-07 Update v2 3d printing parts
    [cog-n18-m1-t1-8-hole-m3.stl, spool-base.stl, spool-lid.stl]
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2025-05-08 m3 holes are now 3.2 mm and the cogs are 2.8mm thick
    [cog-n18-m1-t1-8-hole-m3.stl, cog-n18-m1-t1-8-m3-nut.stl, cog-n18-m1-t1-8-slotted5mm.stl]
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2025-05-10 Fix utime vs. time lib
    [main.py]
2025-05-10 make the cogs 2.5 mm and improve the magnet holder to better fit the 2mm magnets
    [cog-n18-m1-t1-8-hole-m3.stl, cog-n18-m1-t1-8-m3-nut.stl, cog-n18-m1-t1-8-slotted5mm.stl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]
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2025-05-16 Fix error with utime
    [main.py]
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2025-05-18 Change TX Power to 5 rather than 20
    fixes #10
    [boot.py]
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2025-05-27 Flap changes: 7mm Tab / Extra wiggle 0.5 each side / round of Flap corners
    [Flap.dxf]
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2025-06-14 Add floating calibration when passing the hall sensor during operation
    Fixes #5
    [digit.py]
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2025-06-15 Apply the calculated correction when executing the next move
    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
    [digit.py]
2025-06-19 Denote R1 and R7 since they need to be populated on some PCBs after the fact
    See #14
    [splitflap.kicad_pcb]
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2025-07-02 Fix neopixel pin
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
